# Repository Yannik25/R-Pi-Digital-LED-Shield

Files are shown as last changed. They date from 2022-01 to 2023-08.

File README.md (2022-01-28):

# R-Pi-Digital-LED-Shield

Created with KiCad

Main purpose for me was to use this board with my 3D Printer with [OctoPrint](https://octoprint.org) and this add-on: [ws281x-led-status](https://cp2004.gitbook.io/ws281x-led-status/) but will also work with: [rpi_ws281x](https://github.com/jgarff/rpi_ws281x) and similar Software.

## Current status: Designed 
 
## Features
- Power R-Pi through DC Jack or screw terminal (over and reverse voltage Protection)
- Onboard Digital LED
	- can be skipped by bridging the solderpoints at JP1
- Level Shifter from 3.3V to 5V

## The Hardware:

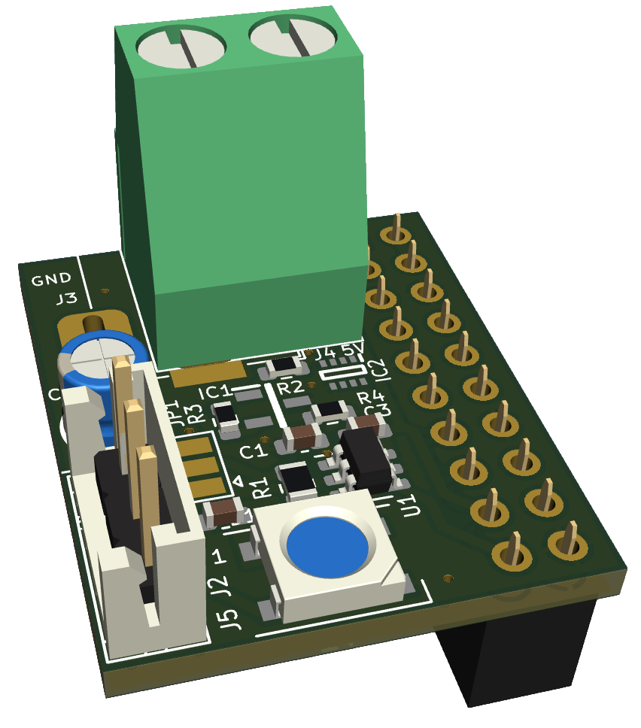
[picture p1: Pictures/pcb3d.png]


## Contributions

Feel free to open Pull Requests or Issues

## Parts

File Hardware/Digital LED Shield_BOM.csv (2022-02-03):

Comment | Designator | Footprint | LCSC
0.1uF | C1 C2 C3 | Capacitor_SMD:C_0603_1608Metric
10uF | C4 | Capacitor_THT:CP_Radial_D4.0mm_P1.50mm
WS2812B | D1 | LED_SMD:LED_WS2812B_PLCC4_5.0x5.0mm_P3.2mm
LM431BCM3X_NOPB | IC1 | LM431BCM3X:SOT95P237X95-3N
LM66200DRLR | IC2 | LM66200DRLR:SOTFL50P160X60-8N
150 | R1 | Resistor_SMD:R_0805_2012Metric
1k | R2 | Resistor_SMD:R_0603_1608Metric
10k | R3 R4 | Resistor_SMD:R_0603_1608Metric
SN74LVC1T45DBV | U1 | Package_TO_SOT_SMD:SOT-23-6

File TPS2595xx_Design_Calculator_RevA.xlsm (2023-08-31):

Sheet: Calculation Sheet
TPS2595xx Design Calculation Tool |  |  |  |  |  |  |  | Table - 1: Device Comparison Table
Constants Cells | Input/SelectCells | Calculation Cells |  |  | Recommended |  |  | Version | VOVC (V) | Enable | Fault Response | QOD | Max Rdson (mΩ) @ 25 degC | Max Rdson (mΩ) @ 125 degC
Error Cells, Must be Fixed | Calculated, but can be over-ridden by user |  |  |  | Value |  |  | TPS259520 | 3.8 | Active High | Latch-off | No | 40 | 58
Parameter | Description | Value | Units | Tolerance |  |  |  | TPS259521 | 3.8 | Active High | Auto-retry | No | 40 | 58
3.3V or 5V or 12V version | Refer Table-1 and select based on OverVoltage Clamp/Cut-off and Active High/Low requirement | TPS259573 |  |  |  |  |  | TPS259525 | 3.8 | Active High | Auto-retry | Yes | 40 | 58
VIN (max) | Maximum Operating input voltage (magnitude) | 5.00 | V |  |  |  |  | TPS259530 | 5.7 | Active High | Latch-off | No | 37 | 53
VUVP | Internal Undervoltage Protection Threshold (VIN Rising) | 2.54 | V | 3.7% |  |  |  | TPS259533 | 5.7 | Active Low | Auto-retry | No | 37 | 53
Cout | Load Capacitance | 10.0 | uF | 10.0% |  |  |  | TPS259535 | 5.7 | Active High | Auto-retry | Yes | 37 | 53
Rlstart | Load at start-up (assumed to be resistive), Refer to Section 9.2.2.3.2 in Datasheet (http://www.ti.com/lit/gpn/tps2595) | 4.0 | Ohm |  | 2.5 |  |  | TPS259540 | 13.7 | Active High | Latch-off | No | 37 | 53
Imax | Maximum continuous load current (magnitude) | 2.0 | A |  |  |  |  | TPS259541 | 13.7 | Active High | Auto-retry | No | 37 | 53
Ilimit | Current Limit, 7.5% higher than maximum continuous load current | 2.15 | A |  |  |  |  | TPS259570 | No Clamp | Active High | Latch-off | No | 37 | 53
VOVC | Over Voltage Clamp | OV Cut-off | V | 4.5% |  |  |  | TPS259571 | No Clamp | Active High | Auto-retry | No | 37 | 53
OVset | Over voltage cut-off threshold (TPS259573 Only) | 5.30 | V |  |  |  |  | TPS259573 | OV Cut-off | Active Low | Auto-retry | No | 37 | 53
OVLO set point calculations (TPS259573)
R1: Pullup at EN/OVLO Pin | Select a value > 100K to keep I_R12 low | 1000.0 | kOhm | 5.0% |  | 2.54 | Release UVLO (VIN Rising)
R2_cal | Calculated value of Resistor at EN/OVLO pin | 292.7 | kOhm |  |  | 5.28 | OV Cutoff (VIN Rising)
SELECT THE VALUE OF RESISTORS AS CLOSEST AVAILABLE VALUE OF R2 |  |  |  |  |  | 4.84 | Release OVLO (VIN Falling)
R2 | Select the closest possible value as R2_cal | 294.00 | kOhm | 5.0% | 294
OV_final | Over Voltage Cut-Off Threshold (VIN Rising) | 5.28 | V | 9.1%
OV_release | Release OVLO (VIN Falling) | 4.84 | V | 9.1%
I_R12 | Current in R1, R2 Branch | 3.86 | uA
Calculations for Ilimit (resistor on ILM Pin)
RILM_Cal | Calculated current limit resistor | 947.87 | Ohm |  |  | 0.1923076923 | Inrush Charging Current
SELECT A ILIMIT RESISTOR WITH THE CLOSEST AVAILABLE VALUE OF Rilm_Cal |  |  |  |  |  | 2.14 | Overload Curr Limit
RILM | Select the closest available value of RLM_cal | 953.00 | Ohm | 5.0% | 953.00
Ilimit_final | Final current Limit Set Point | 2.14 | A | 9.0%
Current Monitor Gain | Current Monitoring Voltage at ILM pin | 263.0 | mV/A | 8.9%
Calculations for SoftStart control (external cap on dVdt pin)
Parameter | Description | Value | Units | Tolerance
I_dVdt | Internal current charging capacitor on dVdt | 2.00 | uA | 10.0%
Gain_dVdt | Internal Gain for dVdt Control | 21.00 | V/V | 3.0%
Icharge_fastest | Charging current when charging at fastest possible rate If this current is < Ilimit, no capacitor is required at dVdT pin | 0.19 | A
Tchg_fastest | when no external capacitor is connected (max. slew rate) | 0.26 | ms | 15.0%
Tchg_req | The charging time required | 0.26 | ms
Icharge_req | Charging (inrush) current desired in the system | 1.60 | A
Cext_dvdt_cal1 | calculated value of capacitor at dVdT pin for required Tcharge | 2.18 | nF
Cext_dvdt_cal2 | calculated value of capacitor at dVdT pin for required Icharge | 0.26 | nF |  | 2.18
SELECT A CAPACITOR WITH THE CLOSEST POSSIBLE VALUE to max(Cext_dvdt_cal1, Cext_dvdt_cal2)
CdVdT_ext | The external capacitor connecetd across dVdT pin (OPEN, or >=3.3nF) | OPEN | nF | 10.0% | OPEN
Icharge | Charging Current as per dVdT setting | 0.19 | A | 17.6%
Does Device Enter Current Limit during start-up? |  | FALSE |  |  | 0.34
Tchg_dVdT | Charging time set | 0.26 | ms | 14.5%
Pd_Cout_startup | Power dissipation due to load cap at start-up | 0.48 | W
Total Power dissipation at Start-up
Pd_Rlstart | Power dissipation due to load resistance at start-up | 1.04 | W
Pd_startup | Total power dissipation at start-up | 1.52 | W
 | Max power dissipation allowed for glitch-free startup for the programmed startup time (20% margin) | 24.00 | W | 15.0%
 | Will the system have glitch-free startup? Look at Thermal Shutdown Limit Plot Tab | YES
Steady state Voltage drop & Power dissipation
Parameter | Description | Value | Units | Tolerance
Vdrop | Maximum voltage drop across device @ 25 degC | 74.00 | mV
Pdiss_Imax | Steady state power dissipation with Max current @ 25degC | 148.00 | mW
Parameters internal to Device
Internal FET Parameters
Parameter | Description | Value | Units | Tolerance
VDSS (max) | FET drain-source voltage rating (maximum) | 20.0 | V
ID(max) | FET drain-source current rating (maximum) | 5.0 | A
Rds(on) | FET maximum Rds(on) at 25degC | 37 | mOhm
Rds(on)_max | FET maximum Rds(on) at 125degC | 53 | mOhm
Thermal Parameters
Tj(max) | Deice maximum junction temperature | 150.0 | C
TA(max) | Maximum ambient temperature of the application | 125.0 | C
RJC | Junction to case (top) Thermal Resistance | 73.3 | C/W
RJA | Junction to ambient thermal resistance | 65.6 | C/W
RJCbot | Junction-to-case(bottom) thermal resistance | 9.8 | C/W
Internal References
UVref | Internal Undervoltage reference (Falling) | 1.10 | V | 6.3%
OVref | Internal Overvoltage reference (Rising) | 1.20 | V | 5.8%
GainIMON | Current monitor gain | 276.00 | uA/A | 7.4%

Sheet: Thermal Shutdown Limit Plot
Thermal Shutdown Time (ms) Vs. Power Dissipation (W) |  |  |  |  | Title of Graph |  | Thermal Shutdown Time Vs. Power Dissipation
Power Dissipation | TA = -40 C | TA = 25 C | TA = 85 C | TA = 125 C
1.3 |  |  |  | 10000.00 | Lable | X-Axis | Power Dissipation (W)
2 |  |  | 10000.00 | 155.96 |  | Y-Axis | Thermal Shutdown time (ms)
3 |  |  | 655.23 | 54.85
4 |  | 10000.00 | 154.50 | 27.43
5 | 10000.00 | 570.84 | 84.80 | 16.57
6 | 2995.87 | 232.87 | 52.84 | 10.19
7 | 663.56 | 124.79 | 30.77 | 6.08
8 | 341.32 | 82.31 | 22.69 | 4.03
9 | 182.83 | 56.52 | 14.95 | 2.91
10 | 125.75 | 42.16 | 11.50 | 2.25
12 | 74.72 | 23.98 | 6.49 | 1.51
14 | 47.60 | 16.01 | 4.12 | 1.12
16 | 32.66 | 10.26 | 2.82 | 0.86
18 | 23.44 | 6.35 | 2.17 | 0.74
20 | 17.87 | 5.03 | 1.71 | 0.63
25 | 9.62 | 3.01 | 1.11 | 0.46
30 | 5.60 | 1.99 | 0.79 | 0.36
35 | 3.68 | 1.60 | 0.66 | 0.29
40 | 2.65 | 1.24 | 0.54 | 0.25
45 | 2.01 | 0.94 | 0.46 | 0.21
50 | 1.60 | 0.81 | 0.39 | 0.19
55 | 1.27 | 0.70 | 0.35 | 0.16
60 | 1.08 | 0.60 | 0.30 | 0.15
 | Pd (W) | Tstart (ms)
 | 1.52 | 0.26

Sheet: Res EIA Tables
Standard EIA Decade Resistor Values
20% | 10% | 5% | 2% | 1% | 0.5%, 0.25%, 0.1%
E6 | E12 | E24 | E48 | E96 | E192
100 | 100 | 100 | 100 | 100 | 100
 |  |  |  |  | 101
 |  |  |  | 102 | 102
 |  |  |  |  | 104
 |  |  | 105 | 105 | 105
 |  |  |  |  | 106
 |  |  |  | 107 | 107
 |  |  |  |  | 109
 |  | 110 | 110 | 110 | 110
 |  |  |  |  | 111
 |  |  |  | 113 | 113
 |  |  |  |  | 114
 |  |  | 115 | 115 | 115
 |  |  |  |  | 117
 |  |  |  | 118 | 118
 |  |  |  |  | 120
 | 120 | 120 | 121 | 121 | 121
 |  |  |  |  | 123
 |  |  |  | 124 | 124
 |  |  |  |  | 126
 |  |  | 127 | 127 | 127
 |  |  |  |  | 129
 |  |  |  | 130 | 130
 |  |  |  |  | 132
 |  | 130 | 133 | 133 | 133
 |  |  |  |  | 135
 |  |  |  | 137 | 137
 |  |  |  |  | 138
 |  |  | 140 | 140 | 140
 |  |  |  |  | 142
 |  |  |  | 143 | 143
 |  |  |  |  | 145
150 | 150 | 150 | 147 | 147 | 147
 |  |  |  |  | 149
 |  |  |  | 150 | 150
 |  |  |  |  | 152
 |  |  | 154 | 154 | 154
 |  |  |  |  | 156
 |  |  |  | 158 | 158
 |  |  |  |  | 160
 |  | 160 | 162 | 162 | 162
 |  |  |  |  | 164
 |  |  |  | 165 | 165
 |  |  |  |  | 167
 |  |  | 169 | 169 | 169
 |  |  |  |  | 172
 |  |  |  | 174 | 174
 |  |  |  |  | 176
 | 180 | 180 | 178 | 178 | 178
 |  |  |  |  | 180
 |  |  |  | 182 | 182
 |  |  |  |  | 184
 |  |  | 187 | 187 | 187
 |  |  |  |  | 189
 |  |  |  | 191 | 191
 |  |  |  |  | 193
 |  | 200 | 196 | 196 | 196
 |  |  |  |  | 198
 |  |  |  | 200 | 200
 |  |  |  |  | 203
 |  |  | 205 | 205 | 205
 |  |  |  |  | 208
 |  |  |  | 210 | 210
 |  |  |  |  | 213
220 | 220 | 220 | 215 | 215 | 215
 |  |  |  |  | 218
 |  |  |  | 221 | 221
 |  |  |  |  | 223
 |  |  | 226 | 226 | 226
 |  |  |  |  | 229
 |  |  |  | 232 | 232
 |  |  |  |  | 234
 |  | 240 | 237 | 237 | 237
 |  |  |  |  | 240
 |  |  |  | 243 | 243
 |  |  |  |  | 246
 |  |  | 249 | 249 | 249
 |  |  |  |  | 252
 |  |  |  | 255 | 255
 |  |  |  |  | 258
 | 270 | 270 | 261 | 261 | 261
 |  |  |  |  | 264
 |  |  |  | 267 | 267
 |  |  |  |  | 271
 |  |  | 274 | 274 | 274
 |  |  |  |  | 277
 |  |  |  | 280 | 280
 |  |  |  |  | 284
 |  | 300 | 287 | 287 | 287
 |  |  |  |  | 291
 |  |  |  | 294 | 294
 |  |  |  |  | 298
 |  |  | 301 | 301 | 301
 |  |  |  |  | 305
 |  |  |  | 309 | 309
 |  |  |  |  | 312
330 | 330 | 330 | 316 | 316 | 316
 |  |  |  |  | 320
 |  |  |  | 324 | 324
 |  |  |  |  | 328
 |  |  | 332 | 332 | 332
 |  |  |  |  | 336
 |  |  |  | 340 | 340
 |  |  |  |  | 344
 |  | 360 | 348 | 348 | 348
 |  |  |  |  | 352
 |  |  |  | 357 | 357
 |  |  |  |  | 361
 |  |  | 365 | 365 | 365
 |  |  |  |  | 370
 |  |  |  | 374 | 374
 |  |  |  |  | 379
 | 390 | 390 | 383 | 383 | 383
 |  |  |  |  | 388
 |  |  |  | 392 | 392
 |  |  |  |  | 397
 |  |  | 402 | 402 | 402
 |  |  |  |  | 407
 |  |  |  | 412 | 412
 |  |  |  |  | 417
 |  | 430 | 422 | 422 | 422
 |  |  |  |  | 427
 |  |  |  | 432 | 432
 |  |  |  |  | 437
 |  |  | 442 | 442 | 442
 |  |  |  |  | 448
 |  |  |  | 453 | 453
 |  |  |  |  | 459
470 | 470 | 470 | 464 | 464 | 464
 |  |  |  |  | 470
 |  |  |  | 475 | 475
 |  |  |  |  | 481
 |  |  | 487 | 487 | 487
 |  |  |  |  | 493
 |  |  |  | 499 | 499
 |  |  |  |  | 505
 |  | 510 | 511 | 511 | 511
 |  |  |  |  | 517
 |  |  |  | 523 | 523
 |  |  |  |  | 530
 |  |  | 536 | 536 | 536
 |  |  |  |  | 542
 |  |  |  | 549 | 549
 |  |  |  |  | 556
 | 560 | 560 | 562 | 562 | 562
 |  |  |  |  | 569
 |  |  |  | 576 | 576
 |  |  |  |  | 583
 |  |  | 590 | 590 | 590
 |  |  |  |  | 597
 |  |  |  | 604 | 604
 |  |  |  |  | 612
 |  | 620 | 619 | 619 | 619
 |  |  |  |  | 626
 |  |  |  | 634 | 634
 |  |  |  |  | 642
 |  |  | 649 | 649 | 649
 |  |  |  |  | 657
 |  |  |  | 665 | 665
 |  |  |  |  | 673
680 | 680 | 680 | 681 | 681 | 681
 |  |  |  |  | 690
 |  |  |  | 698 | 698
 |  |  |  |  | 706
 |  |  | 715 | 715 | 715
 |  |  |  |  | 723
 |  |  |  | 732 | 732
 |  |  |  |  | 741
 |  | 750 | 750 | 750 | 750
 |  |  |  |  | 759
 |  |  |  | 768 | 768
 |  |  |  |  | 777
 |  |  | 787 | 787 | 787
 |  |  |  |  | 796
 |  |  |  | 806 | 806
 |  |  |  |  | 816
 | 820 | 820 | 825 | 825 | 825
 |  |  |  |  | 835
 |  |  |  | 845 | 845
 |  |  |  |  | 856
 |  |  | 866 | 866 | 866
 |  |  |  |  | 876
 |  |  |  | 887 | 887
 |  |  |  |  | 898
 |  | 910 | 909 | 909 | 909
 |  |  |  |  | 920
 |  |  |  | 931 | 931
 |  |  |  |  | 942
 |  |  | 953 | 953 | 953
 |  |  |  |  | 965
 |  |  |  | 976 | 976
 |  |  |  |  | 988
1000 | 1000 | 1000 | 1000 | 1000 | 1000 | End Values Required for Processing

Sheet: Cap Tables
Standard Capacitor Values (http://www.rfcafe.com/references/electrical/capacitor-values.htm)
pF | nF | µF | mF
1.0 | 1.0 | 1.0 | 1.0
1.1 | 1.1
1.2 | 1.2
1.3 | 1.3
1.5 | 1.5 | 1.5 | 1.5
1.6 | 1.6
1.8 | 1.8
2.0 | 2.0
2.2 | 2.2 | 2.2 | 2.2
2.4 | 2.4
2.7 | 2.7
3.0 | 3.0
3.3 | 3.3 | 3.3 | 3.3
3.6 | 3.6 | 4.7
3.9 | 3.9 | 4.7
4.3 | 4.3 | 4.7
4.7 | 4.7 | 4.7 | 4.7
5.1 | 5.1 | 6.8
5.6 | 5.6 | 6.8
6.2 | 6.2 | 6.8
6.8 | 6.8 | 6.8 | 6.8
7.5 | 7.5 | 10.0
8.2 | 8.2 | 10.0
9.1 | 9.1 | 10.0
10.0 | 10.0 | 10.0 | 10.0
11.0 | 15.0 | 15.0
12.0 | 15.0 | 15.0
13.0 | 15.0 | 15.0
15.0 | 15.0 | 15.0
16.0 | 22.0 | 22.0
18.0 | 22.0 | 22.0
20.0 | 22.0 | 22.0
22.0 | 22.0 | 22.0
24.0 | 33.0 | 33.0
27.0 | 33.0 | 33.0
30.0 | 33.0 | 33.0
33.0 | 33.0 | 33.0
36.0 | 47.0 | 47.0
39.0 | 47.0 | 47.0
43.0 | 47.0 | 47.0
47.0 | 47.0 | 47.0
51.0 | 68.0 | 68.0
56.0 | 68.0 | 68.0
62.0 | 68.0 | 68.0
68.0 | 68.0 | 68.0
75.0 | 100.0 | 100.0
82.0 | 100.0 | 100.0
91.0 | 100.0 | 100.0
100.0 | 100.0 | 100.0
110.0 | 150.0 | 150.0
120.0 | 150.0 | 150.0
130.0 | 150.0 | 150.0
150.0 | 150.0 | 150.0
160.0 | 220.0 | 220.0
180.0 | 220.0 | 220.0
200.0 | 220.0 | 220.0
220.0 | 220.0 | 220.0
240.0 | 330.0 | 330.0
270.0 | 330.0 | 330.0
300.0 | 330.0 | 330.0
330.0 | 330.0 | 330.0
360.0 | 470.0 | 470.0
390.0 | 470.0 | 470.0
430.0 | 470.0 | 470.0
470.0 | 470.0 | 470.0
510.0 | 680.0 | 680.0
560.0 | 680.0 | 680.0
620.0 | 680.0 | 680.0
680.0 | 680.0 | 680.0
750.0 | 1000.0 | 1000.0
820.0 | 1000.0 | 1000.0
910.0 | 1000.0 | 1000.0

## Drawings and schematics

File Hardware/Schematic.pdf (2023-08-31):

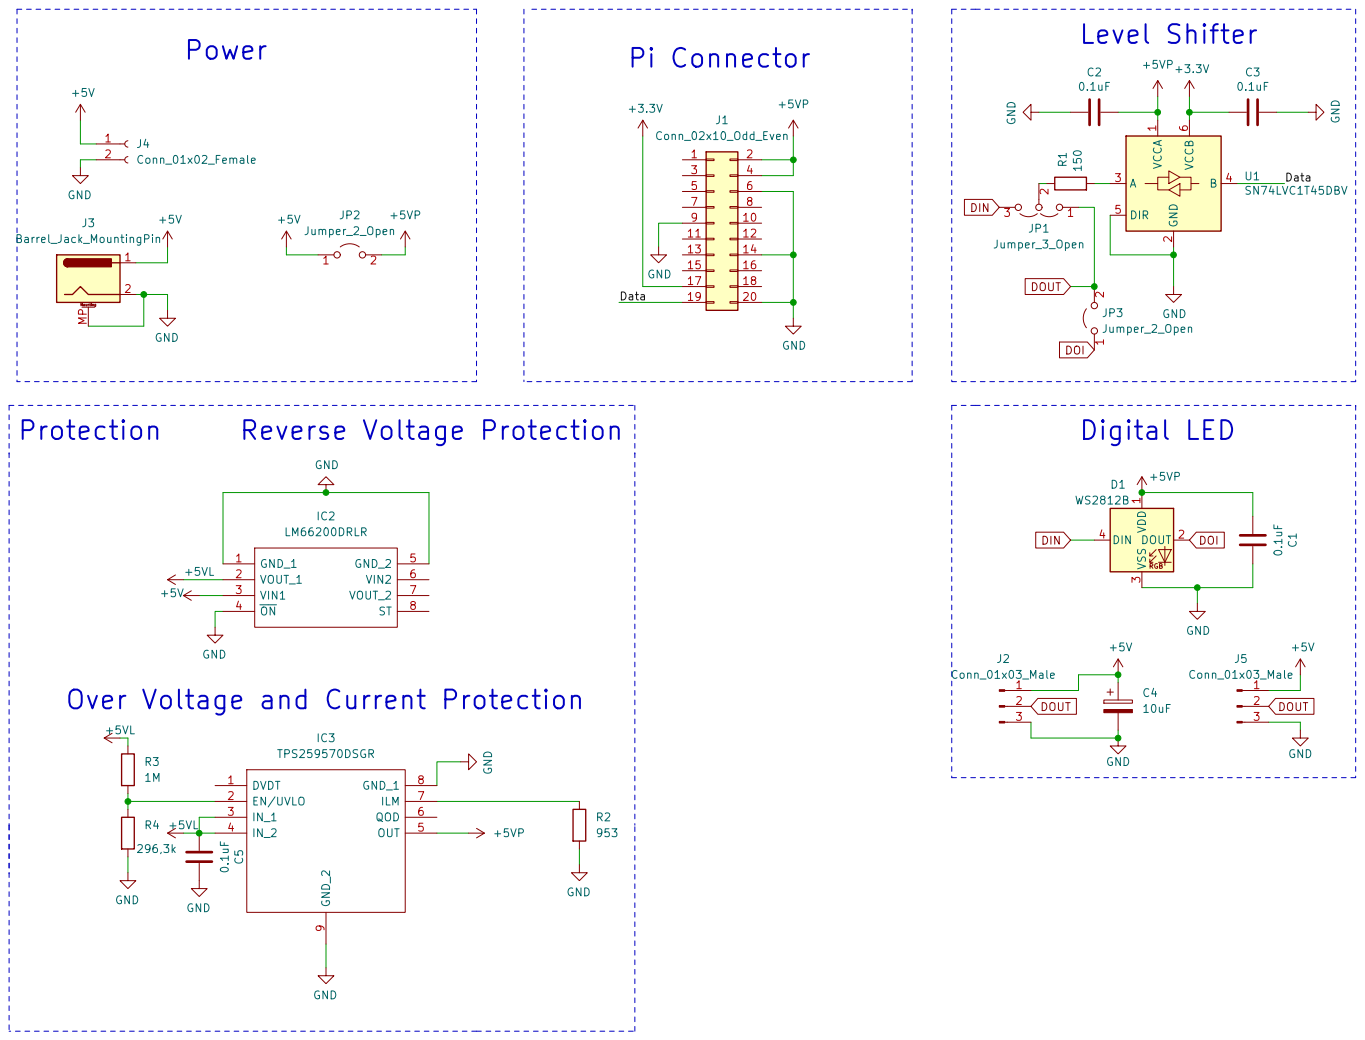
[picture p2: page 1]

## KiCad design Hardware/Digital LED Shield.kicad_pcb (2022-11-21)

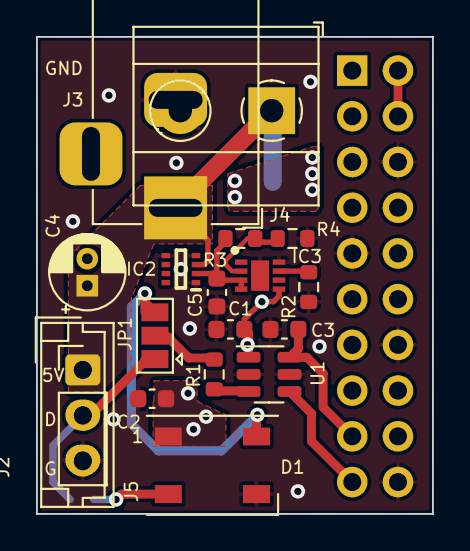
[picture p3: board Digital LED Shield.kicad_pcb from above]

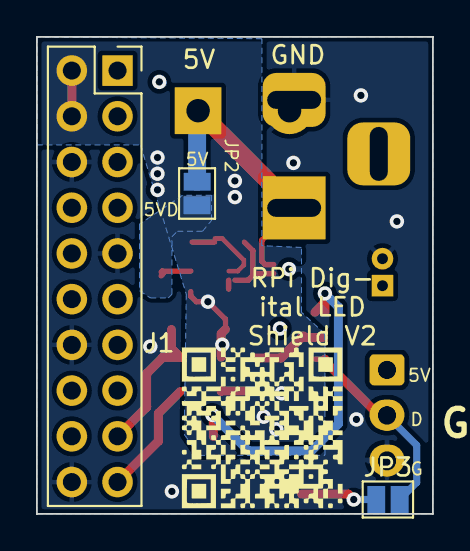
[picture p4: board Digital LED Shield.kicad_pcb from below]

Board: 2 copper layers, 22.0 x 26.5 mm, 21 parts (3 on the bottom side), 13 nets.

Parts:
C1, C2, C3, C5: 0.1uF; C_0603_1608Metric
C4: 10uF; CP_Radial_D4.0mm_P1.50mm
D1: WS2812B; LED_WS2812B_PLCC4_5.0x5.0mm_P3.2mm
IC2: LM66200DRLR; SOTFL50P160X60-8N
IC3: TPS259570DSGR; SON50P200X200X80-9N
J1: Conn_02x10_Odd_Even; PinSocket_2x10_P2.54mm_Vertical
J2: Conn_01x03_Male; PinHeader_1x03_P2.54mm_Vertical
J3: Barrel_Jack_MountingPin; BarrelJack_Horizontal
J4: Conn_01x02_Female; TerminalBlock_Phoenix_MKDS-1,5-2-5.08_1x02_P5.08mm_Horizont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
J5: Conn_01x03_Male; JST_EH_B3B-EH-A_1x03_P2.50mm_Vertical
JP1: Jumper_3_Open; SolderJumper-3_P1.3mm_Open_Pad1.0x1.5mm
JP2, JP3: Jumper_2_Open; SolderJumper-2_P1.3mm_Open_Pad1.0x1.5mm
R1: 150; R_0603_1608Metric
R2: 953; R_0603_1608Metric
R3: 1k; R_0603_1608Metric
R4: 296,3k; R_0603_1608Metric
U1: SN74LVC1T45DBV; SOT-23-6

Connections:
+3V3: C3.2, J1.17, U1.6 (VCCB)
+5V: C4.1, IC2.3 (VIN1), J2.1, J3.1, J4.1, J5.1, JP2.1 (A)
+5VL: C5.2, IC2.2 (VOUT_1), IC3.3 (IN_1), IC3.4 (IN_2), R3.1
+5VP: C1.2, C2.1, D1.1 (VDD), IC3.5 (OUT), J1.2, J1.4, JP2.2 (B), U1.1 (VCCA)
/Data: J1.19, U1.4 (B)
DIN: D1.4 (DIN), JP1.3 (B)
DOI: D1.2 (DOUT), JP3.1 (A)
DOUT: J2.2, J5.2, JP1.1 (A), JP3.2 (B)
GND: C1.1, C2.2, C3.1, C4.2, C5.1, D1.3 (VSS), IC2.1 (GND_1), IC2.4 (~ON), IC2.5 (GND_2), IC3.8 (GND_1), IC3.9 (GND_2), J1.6, J1.9, J1.14, J1.20, J2.3, J3.2, J4.2, J5.3, R2.2, R4.2, U1.2 (GND), U1.5 (DIR)
unnamed: IC3.2 (EN/UVLO), R3.2, R4.1
unnamed: IC3.7 (ILM), R2.1
unnamed: JP1.2 (C), R1.1
unnamed: R1.2, U1.3 (A)

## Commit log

2022-01-14 initial release
    [Digital LED Shield.kicad_pcb, Digital LED Shield.kicad_sch]
2022-01-20 add protection
    [Digital LED Shield.kicad_pcb, Digital LED Shield.kicad_sch]
2022-01-28 Add protection and screw terminal
    [Digital LED Shield.kicad_pcb, Digital LED Shield.kicad_sch]
2022-02-03 Add ordered Version V1
    [Digital LED Shield.kicad_pcb, Digital LED Shield.kicad_sch, Digital LED Shield_BOM.csv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]
2022-02-04 Create RPI Digital LED Shield Gerber.zip
2022-05-09 change lm431 to TPS2420
    [Digital LED Shield.kicad_pcb, Digital LED Shield.kicad_sch]
2022-05-09 update sch and pcb
    [Digital LED Shield.kicad_pcb, Digital LED Shield.kicad_sch]
2022-05-09 update RPI Shield
    [Digital LED Shield.kicad_pcb]
2022-06-03 Update Digital LED Shield.kicad_pcb
    [Digital LED Shield.kicad_pcb]
2022-06-03 add Gerber
    [Digital LED Shield.kicad_pcb, Digital LED Shield.kicad_sch]
2022-11-21 add eFuse for Overvoltage and Overcurrent protection
    [Digital LED Shield.kicad_pcb, Digital LED Shield.kicad_sch]
2023-08-30 Delete Schematic.pdf
    delete old schematic
2023-08-31 update Overvoltage protection resistor value
    [Digital LED Shield.kicad_sch]
